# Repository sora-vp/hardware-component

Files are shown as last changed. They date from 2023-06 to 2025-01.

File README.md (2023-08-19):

<p align="center">
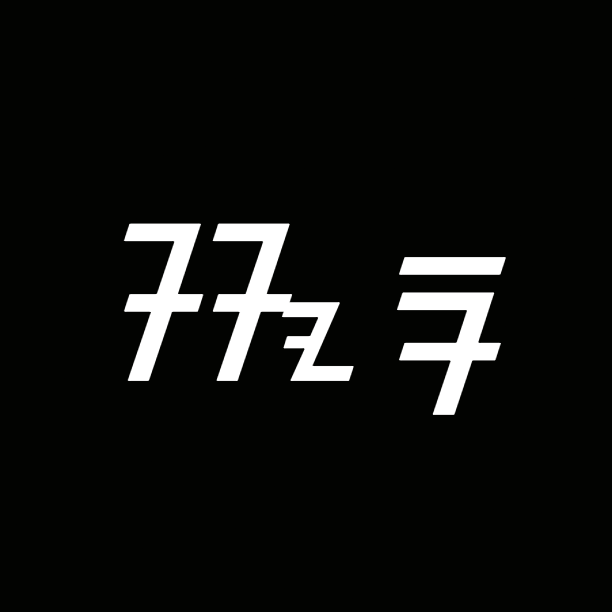
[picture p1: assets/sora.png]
   
   <h1 align="center">SORA BUTTON MODULE</h1>
</p>

Ini adalah repositori pendukung [sora](https://github.com/reacto11mecha/sora) membuat tombol custom untuk memilih kandidat. Harapannya jika tidak ada perangkat touchscreen dan ada orang yang tidak bisa mengoperasikan komputer dengan baik masih bisa ikut memilih seperti biasanya.

## Cara pembuatan tombol custom

Di bawah ini saya akan menjelaskan bagaimana cara membuat modul tombol mandiri. Jika ada hal yang ingin dirubah, silahkan ubah sesuka hati sesuai bahan dan kreativitas masing-masing.

## Siapkan alat bahan

Pertama, siapkan terlebih dahulu alat dan bahan seperti

1. Gunting / cutter
2. Arduino Nano v3.0
3. Kardus bekas
4. Solder
5. Timah
6. Kabel (5 Meter, minimal 16 AWG)
7. Push button (8 buah)
8. Lem tembak beserta isinya.
9. PCB bolong (8x16cm)

> Catatan, untuk kardus dan arduino bisa menyesuaikan budget yang ada. Untuk tutorial di readme ini akan menggunakan kardus sebagai boxnya.

### 1. Buat kerangka

Hasil percobaan yang saya lakukan menghasilkan ukuran kerangka dengan bentuk jaring-jaring balok yang terlihat seperti ini.

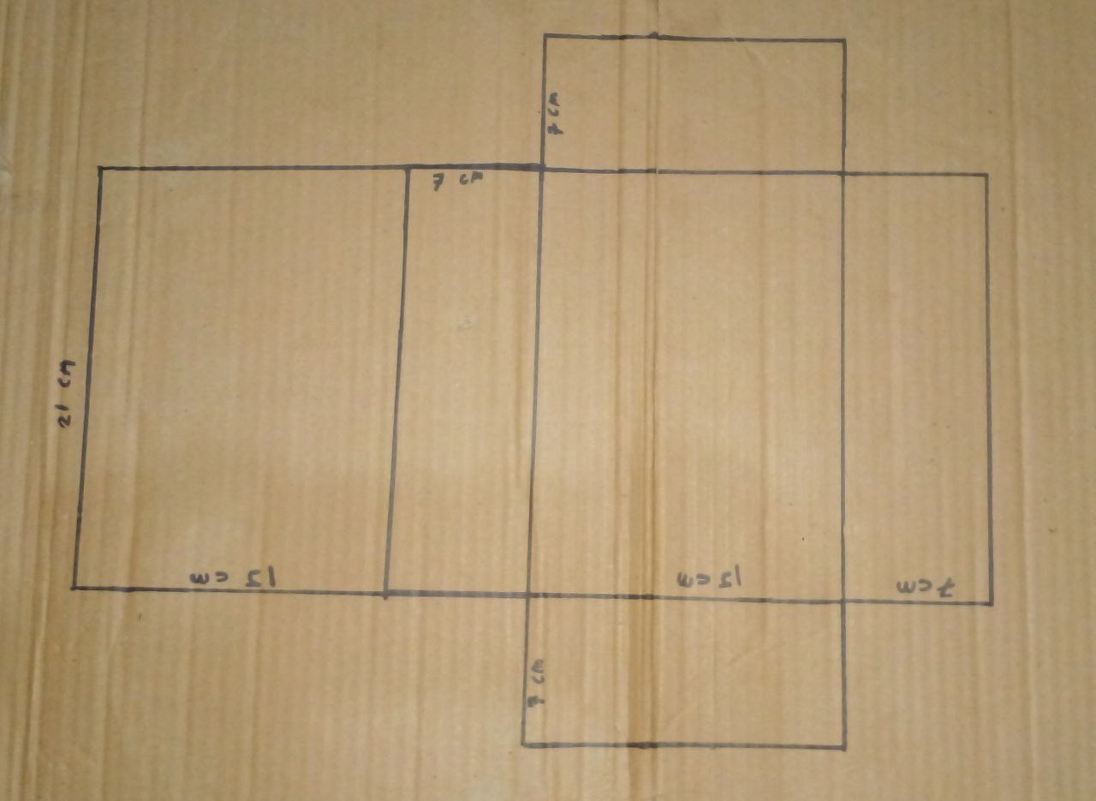
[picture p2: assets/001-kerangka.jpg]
Gambar kerangka kardus


Balok ini memiliki panjang 21 cm, lebar 15 cm, dan tinggi 7 cm.

### 2. Potong setiap bagian sebanyak dua lembar

Jika kerangka sudah dibuat, potong setiap bagian menjadi dua lembar kardus. Kemudian rekatkan menggunakan lem tembak supaya kekuatan kardus tidak terlalu lemah.

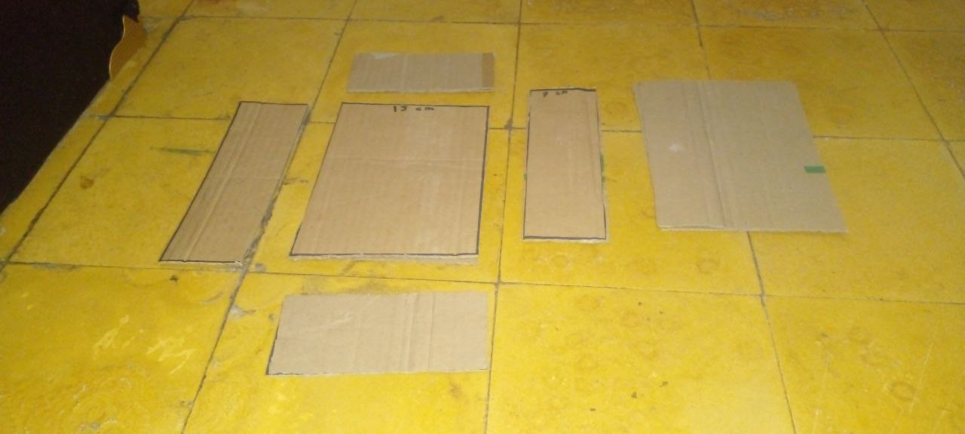
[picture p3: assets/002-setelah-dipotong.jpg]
Gambar bagian-bagian kecil kardus


### 3. Mengatur jarak antar tombol

Untuk penempatan tombol, gunakan jaring-jaring balok dari kardus yang sudah dibuat menggunakan bagian tutup balok.

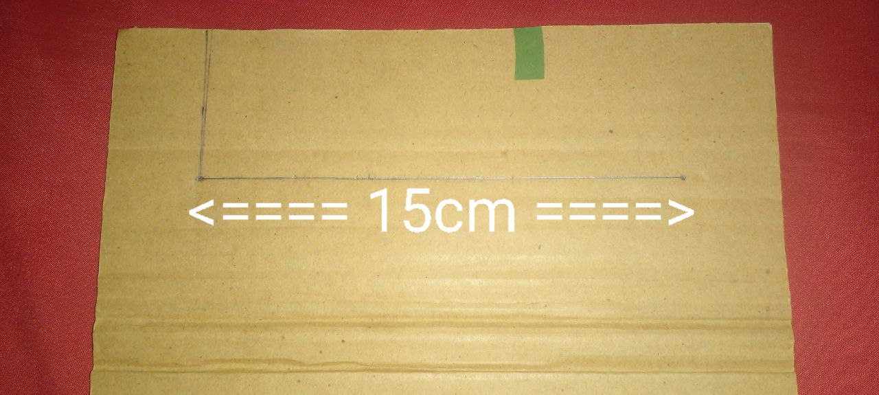
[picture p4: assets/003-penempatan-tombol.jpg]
Ukuran panjang tombol


Panjang keseluruhan peletakan tombol itu 15cm untuk tombol kandidat dan aksi pilih dan pembatalan.

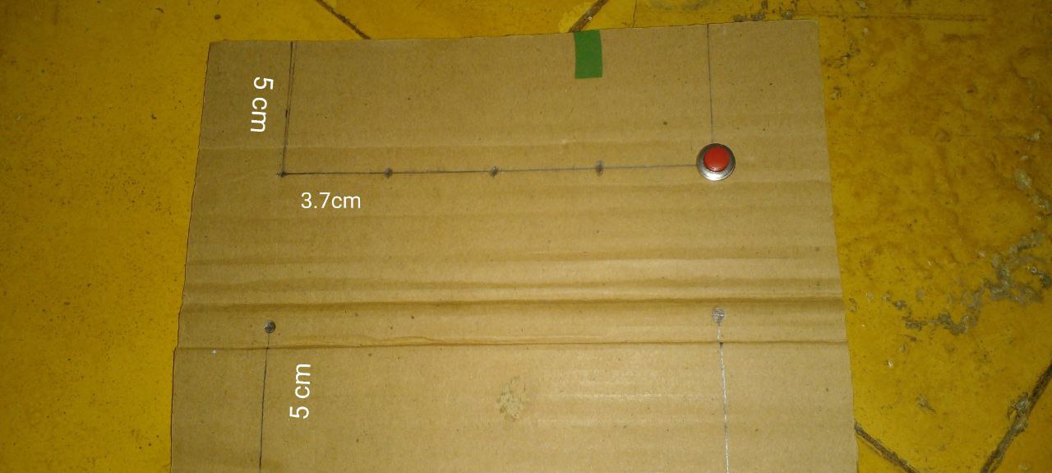
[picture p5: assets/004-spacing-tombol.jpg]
Gambar penjarakan tombol


Untuk tombol angka yang nantinya digunakan untuk memilih kandidat, beri jarak 5cm dari atas juga 3 cm dari kanan dan kiri. Jarak antar tombol memiliki panjang 3.7cm supaya sesuai.

Tombol batal dan pilih juga beri jarak dari bawah. Tombol batal mengikuti posisi tombol nomor 1, sedangkan tombol pilih mengikuti posisi tombol nomor 5.

Tombol reload diposisikan sejajar dengan tombol nomor 5, posisi berjarak 3 cm dari kiri, 3.5 cm dari atas.

Jika sudah pasang lubangi titik-titik yang sudah dibuat, lalu pasang tombol yang sebelumnya sudah disiapkan. Kurang lebih hasilnya akan seperti ini.

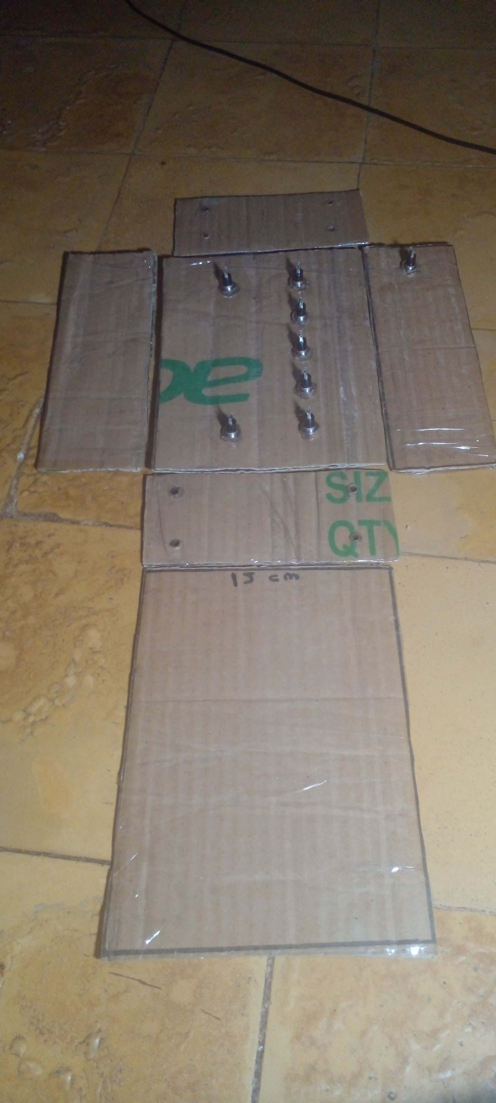
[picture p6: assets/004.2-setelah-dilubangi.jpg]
Gambar 1 setelah sketsa dilubangi


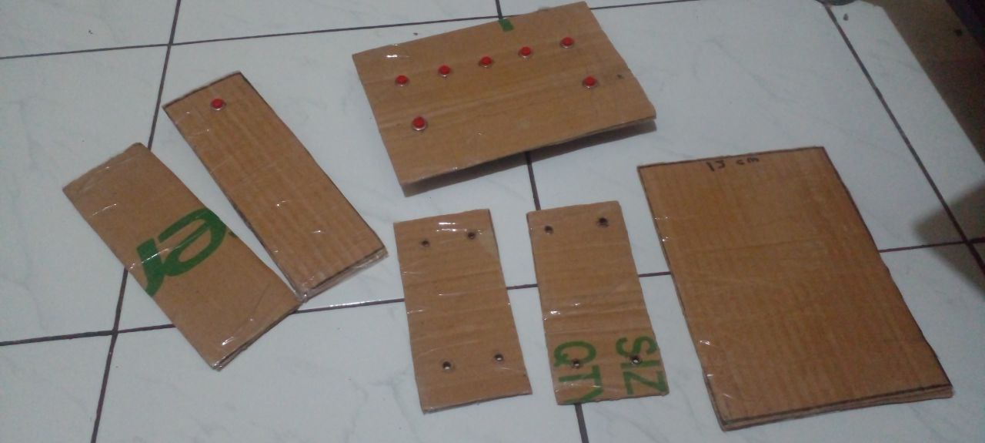
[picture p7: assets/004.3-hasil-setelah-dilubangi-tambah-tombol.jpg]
Gambar 2 setelah sketsa dilubangi


> Jika memperhatikan gambar di atas ada 4 lubang di dua sisi kanan dan kiri kardus, itu berfungsi sebagai lubang udara. Ini opsional tetapi

### 4. Merancang sirkuit

Desain tombol ini sangat berdasar pada artikel [makeuseof.com](https://www.makeuseof.com/tag/make-custom-shortcut-buttons-arduino/) yang membahas cara membuat tombol sendiri. Kurang lebih gambar sirkuitnya sama, yang membedakan saya hanya menggunakan D2 sampai D9 saja.

Gambar sirkuit dari makeuseof

Gambar di atas merupakan gambaran dasar sirkuitnya. Jika diperhatikan pin D2 sampai D9 menggunakan transistor 10k ohm yang warna emas terhubung ke pin arduino, sedangkan seluruh resisto warna coklat akan tersambung ke pin ground atau `GND`.

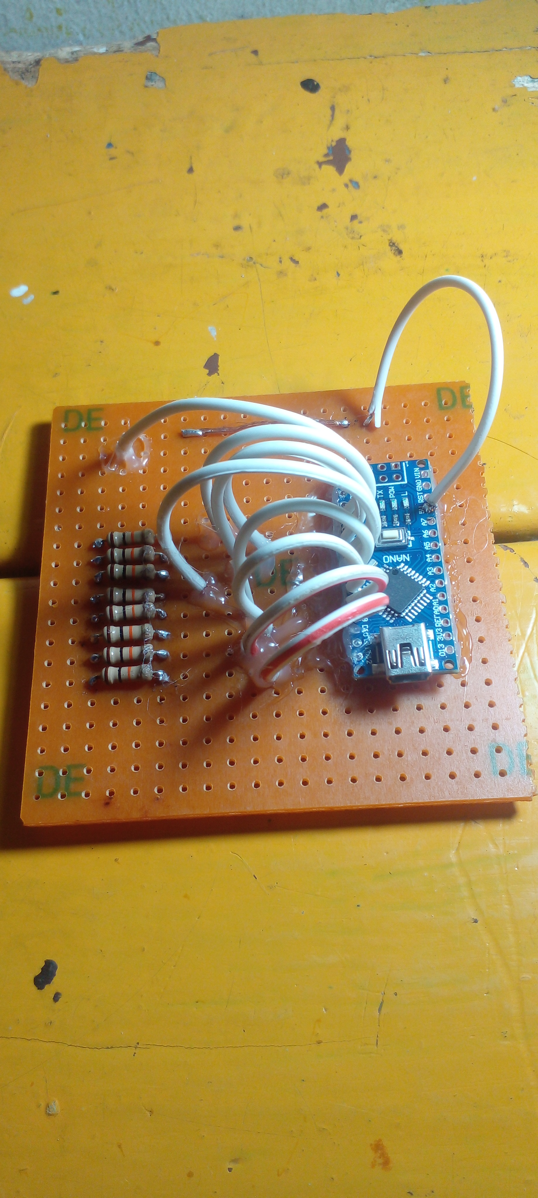
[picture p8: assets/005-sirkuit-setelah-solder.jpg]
Gambar sirkuit setelah di solder


Gambar di atas adalah versi yang nantinya akan digunakan.

### 5. Menambahkan kabel ke tombol dan lem tombol

Jika sudah merancang sirkuitnya, sekarang sambungkan kabel ke tombol dengan cara menyolder kabel supaya sambungannya kuat. Berlaku untuk semua tombol, kira-kira tampaknya akan terlihat seperti dua gambar dibawah ini.

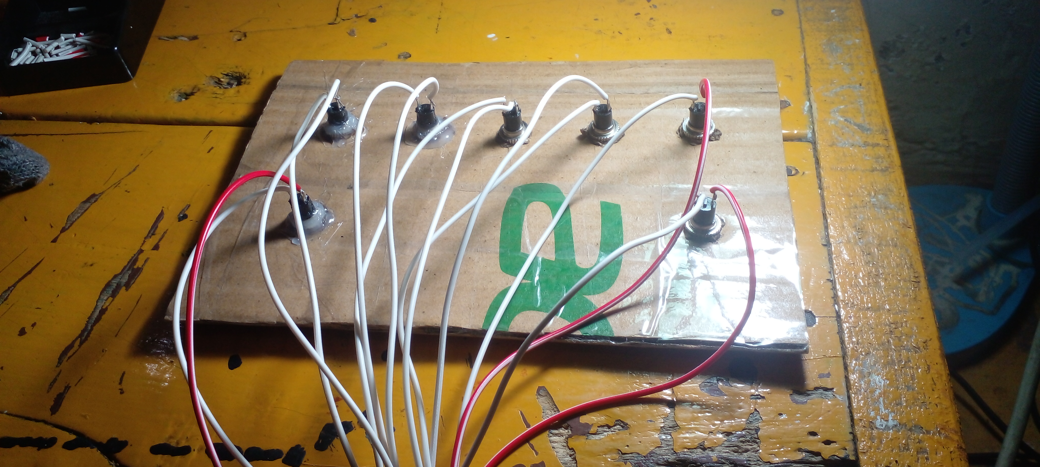
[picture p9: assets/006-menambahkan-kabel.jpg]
Gambar 1 menambahkan kabel ke tombol


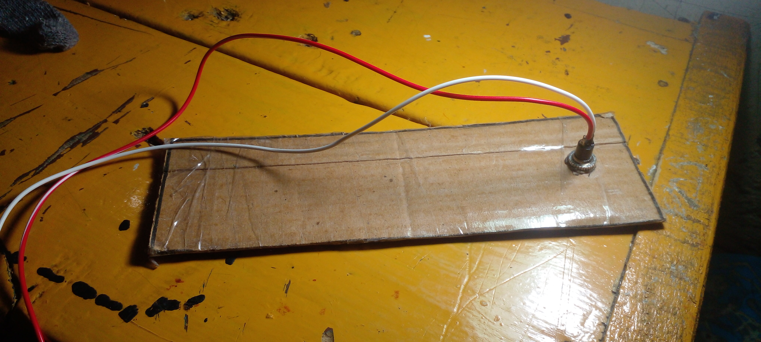
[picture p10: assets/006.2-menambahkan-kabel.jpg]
Gambar 2 menambahkan kabel ke tombol


Jika sudah, lem semua tombol supaya tidak mudah lepas dari kardus. Hal ini juga dapat mengurangi kerusakan jika tombol ditekan terlalu keras.

### 6. Menyambungkan kabel ke sirkuit

Jika sudah menambahkan kabel ke tombol-tombol yang ada, saatnya menyambungkan tombol ke sirkuit yang sudah dibuat sebelumnya. `5V` terhubung ke satu sisi dari tombol, sisi yang lain akan terhubung ke digital pin dari arduino.

Jika berpatokan pada kode di bawah ini,

```ino
const int ESC_PIN = 4;
const int KEYBIND_1_PIN = 9;
const int KEYBIND_2_PIN = 8;
const int KEYBIND_3_PIN = 7;
const int KEYBIND_4_PIN = 6;
const int KEYBIND_5_PIN = 5;
const int ENTER_PIN = 3;
const int RELOAD_PIN = 2;
```

Maka

- Tombol 1 => Pin D9
- Tombol 2 => Pin D8
- Tombol 3 => Pin D7
- Tombol 4 => Pin D6
- Tombol 5 => Pin D5
- Tombol Escape (Kiri Bawah) => Pin D4
- Tombol Enter (Kanan Bawah) => Pin D3
- Tombol Reload (Sisi depan, bersamaan port usb) => Pin D2

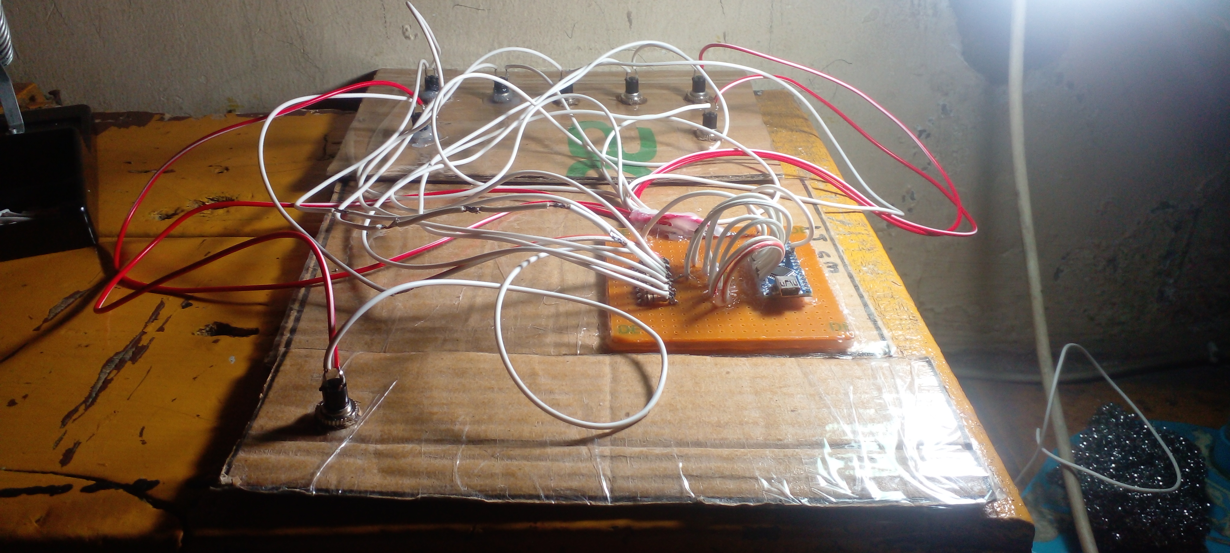
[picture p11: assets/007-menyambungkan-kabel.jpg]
Gambar menyambungkan kabel keseluruhan kabel


Gambar setelah di sambungkan menggunakan solder akan terlihat seperti ini.

> Sekali lagi, sesuaikan dengan kebutuhan

### 7. Memposisikan sirkuit dengan papan reload

Pada tahap ini, posisikan pcb dengan arduino yang sudah di rekatkan dengan kardus yang memiliki tombol reload. Disarkankan posisi yang bisa dipasang port mini usb ke arduino berada berseberangan dengan tombol reload. Jika sudah, buat lubang kotak untuk tempat terhubungnya arduino melalui USB.

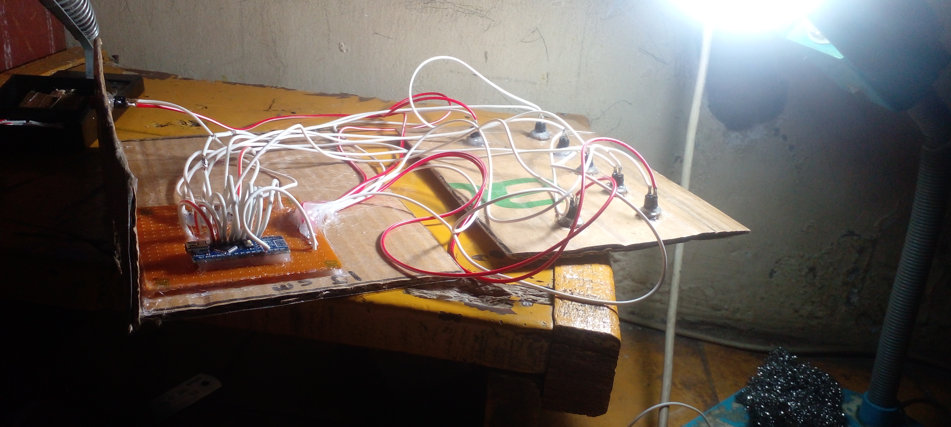
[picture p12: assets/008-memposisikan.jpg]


Tampak depan setelah dilubangi.

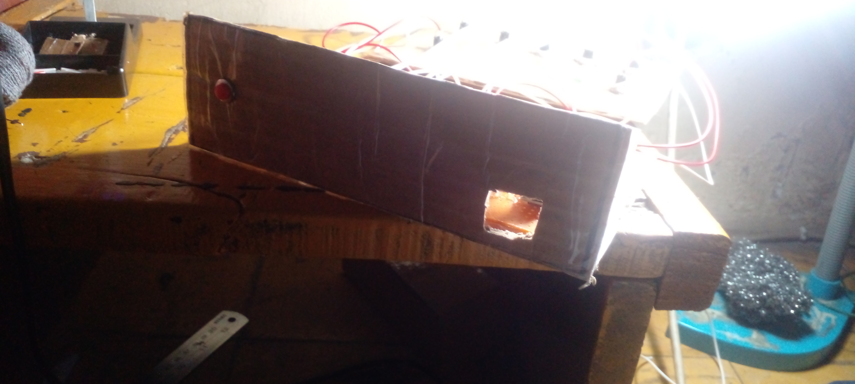
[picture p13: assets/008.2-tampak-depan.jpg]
Tampak depan


### 8. Lem semua komponen

Jika dirasa sudah beres, lem semua komponen yang akhirnya tampak seperti kotak yang memiliki tombol. Hasil akhirnya tampak seperti dibawah ini.

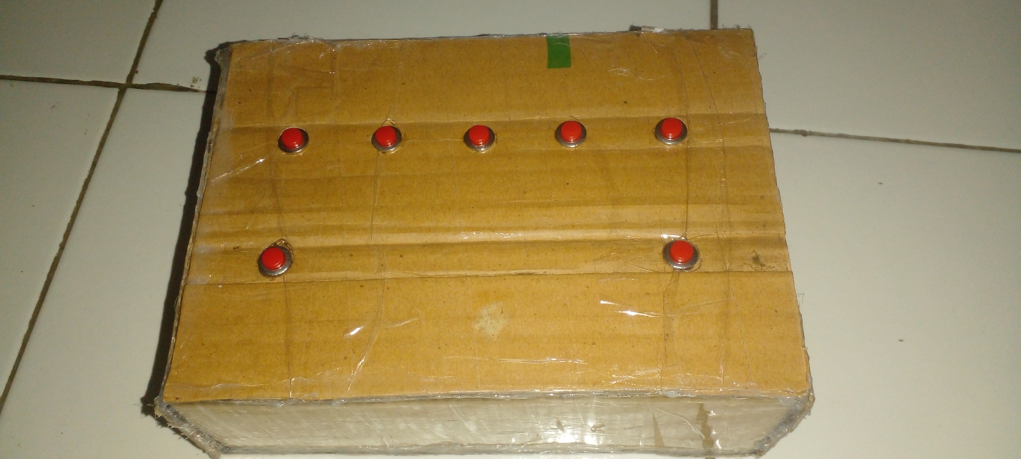
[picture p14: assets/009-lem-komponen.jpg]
Tampak atas setelah di lem


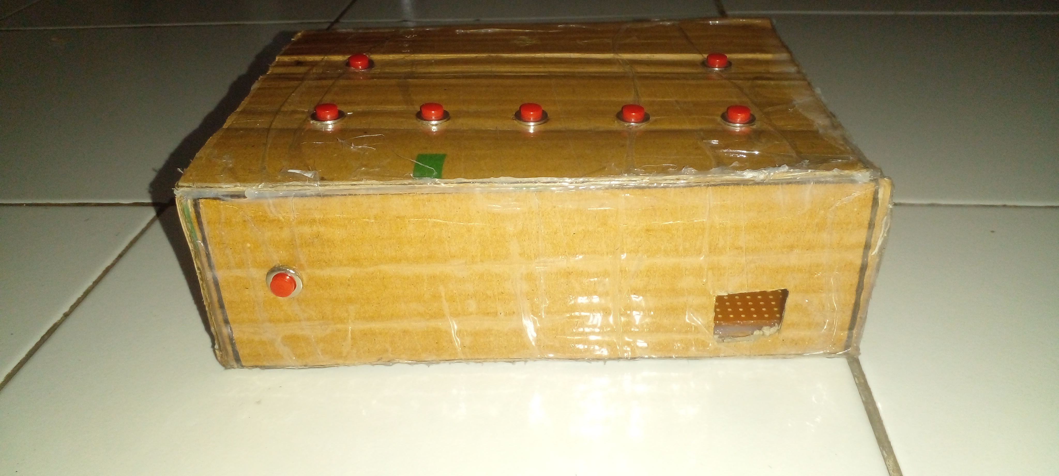
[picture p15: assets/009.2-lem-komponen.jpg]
Tampak depan setelah di lem


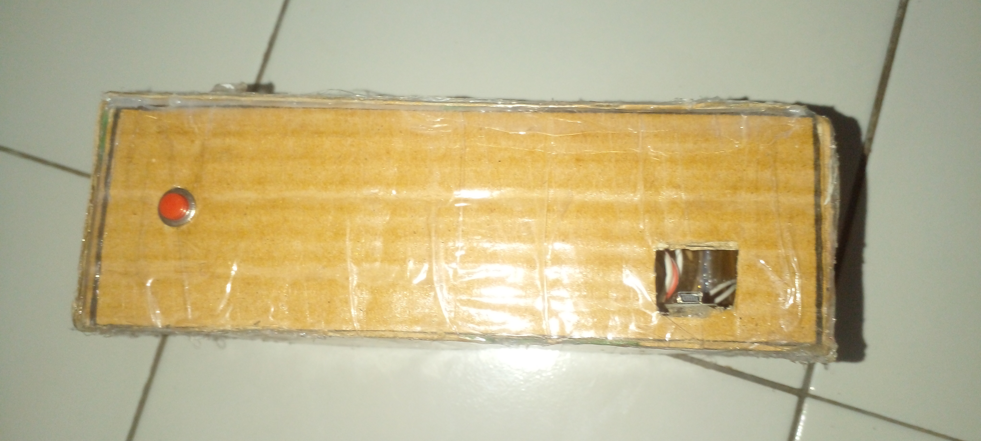
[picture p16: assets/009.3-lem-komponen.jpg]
Tampak sisi depan setelah di lem


### 9. Finishing

Dibagian ini, silahkan di hias dan setiap tombol yang ada diberi keterangan supaya peserta pemilihan mengetahui fungsi dari setiap tombol.

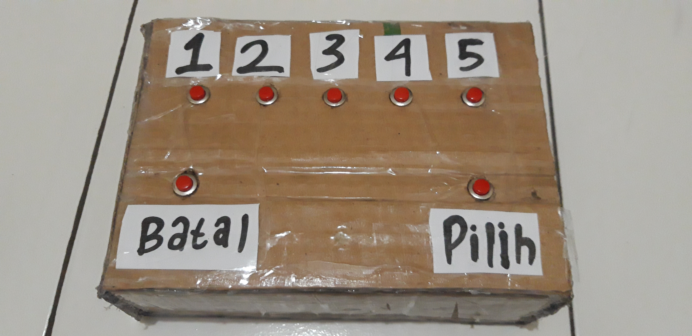
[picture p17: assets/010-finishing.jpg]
Tampak atas setelah finishing


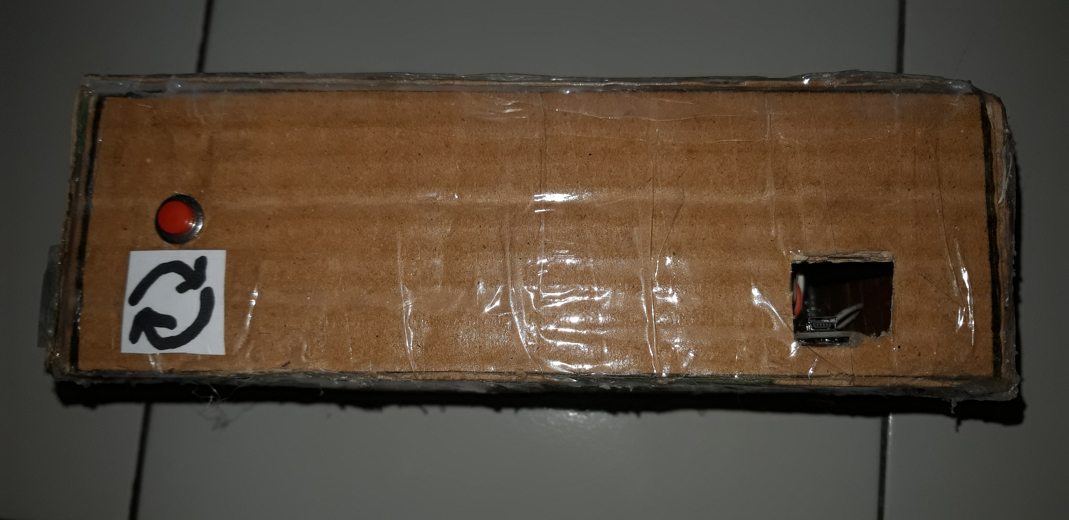
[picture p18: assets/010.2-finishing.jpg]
Tampak depan setelah finishing


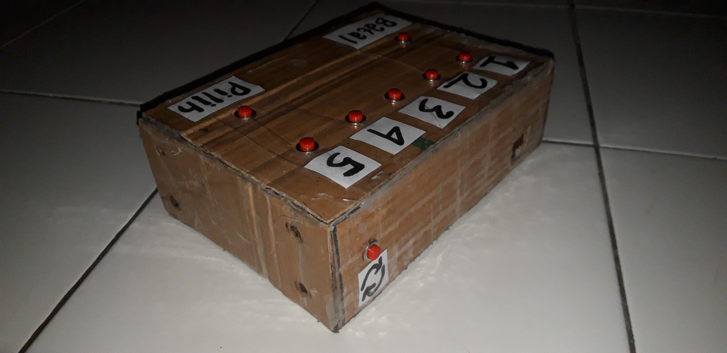
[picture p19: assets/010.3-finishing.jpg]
Tampak sisi depan setelah finishing


## Upload sketch ke arduino

TODO: penjelasan

## Sumber Lain

- https://www.makeuseof.com/tag/make-custom-shortcut-buttons-arduino/

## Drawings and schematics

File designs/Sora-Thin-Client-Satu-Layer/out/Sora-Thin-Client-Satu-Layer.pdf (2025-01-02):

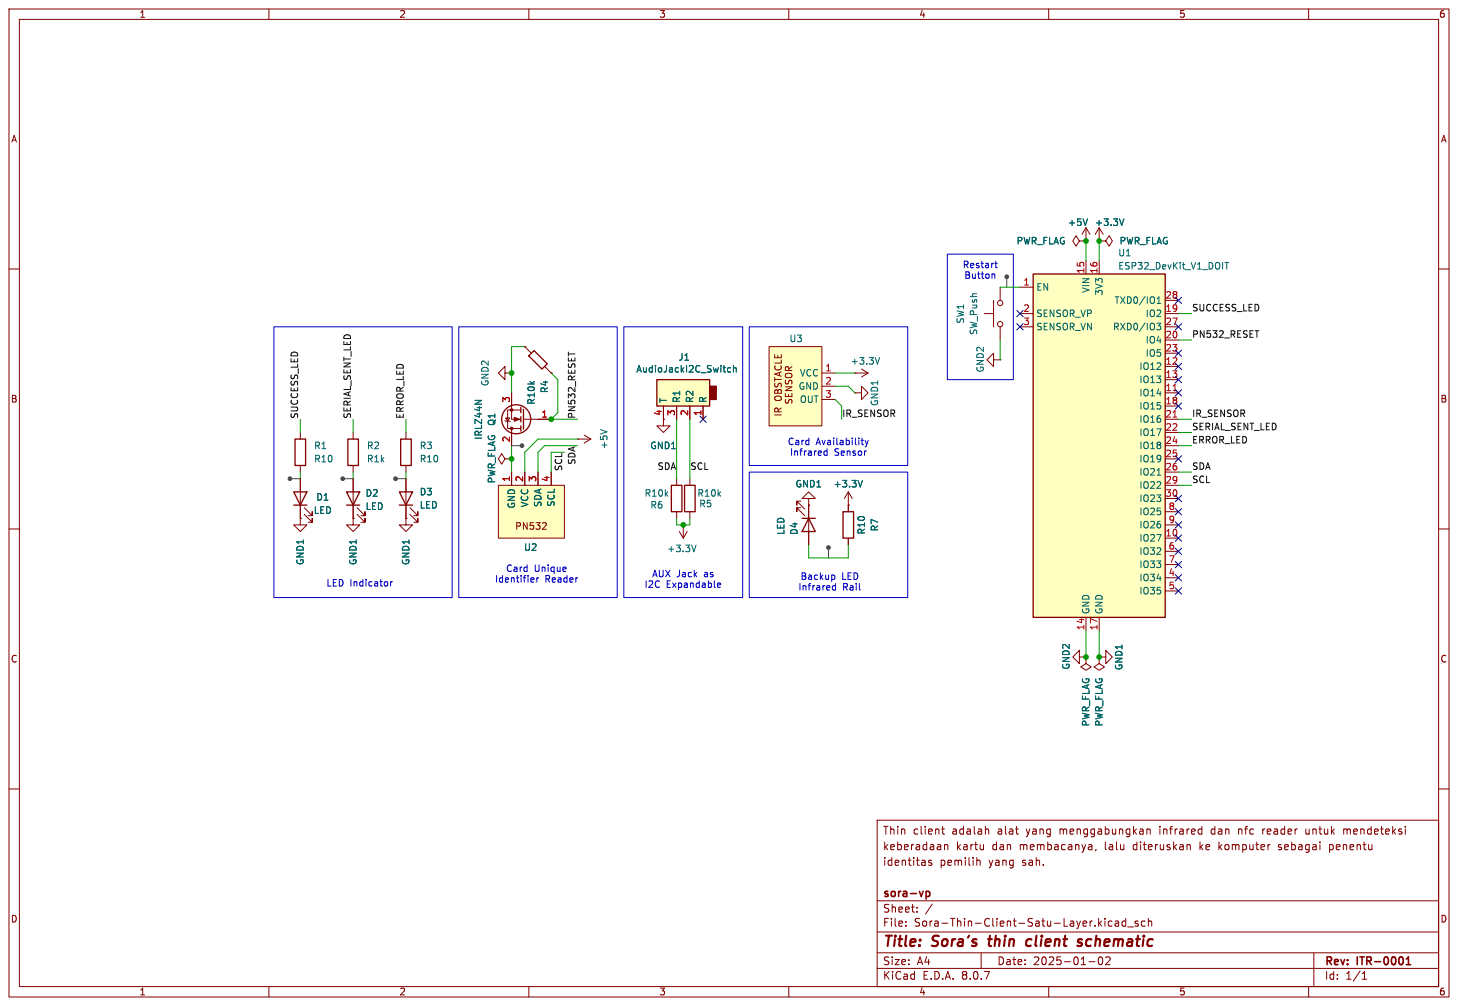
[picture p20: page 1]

Restart Button Card Unique

SENSOR VCC 1 GND 2 OUT 3 U3 R4 R10k GND1 +5V GND2 R10 R7

File: Sora-Thin-Client-Satu-Layer.kicad_sch Sheet: / sora-vp

Id: 1/1 Title: Sora's thin client schematic

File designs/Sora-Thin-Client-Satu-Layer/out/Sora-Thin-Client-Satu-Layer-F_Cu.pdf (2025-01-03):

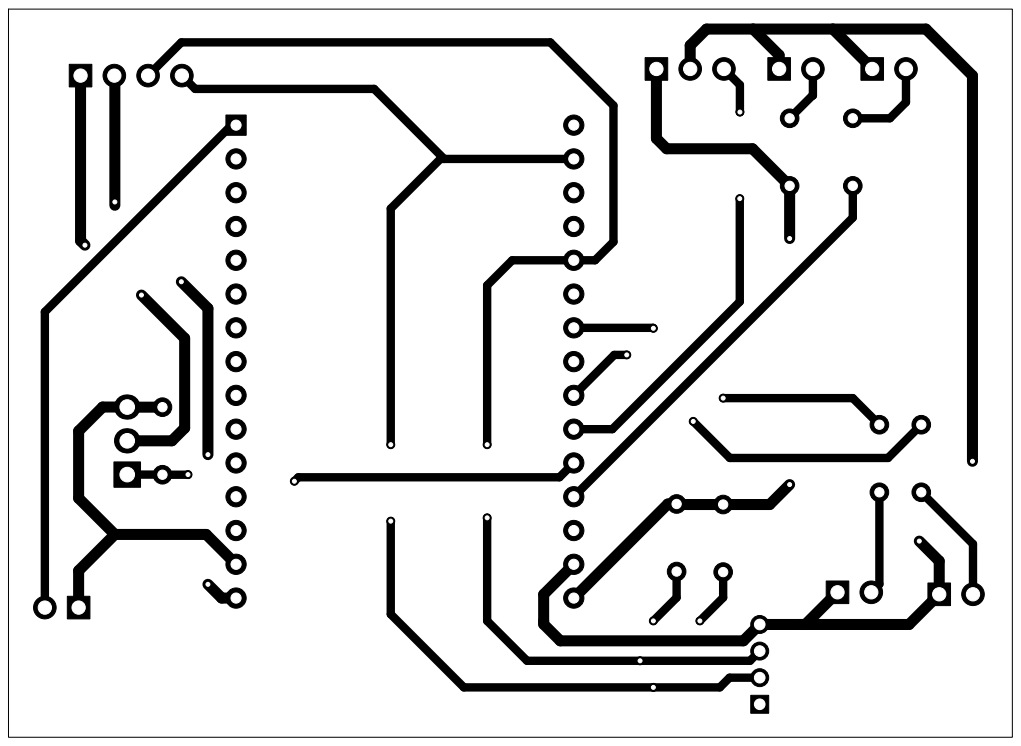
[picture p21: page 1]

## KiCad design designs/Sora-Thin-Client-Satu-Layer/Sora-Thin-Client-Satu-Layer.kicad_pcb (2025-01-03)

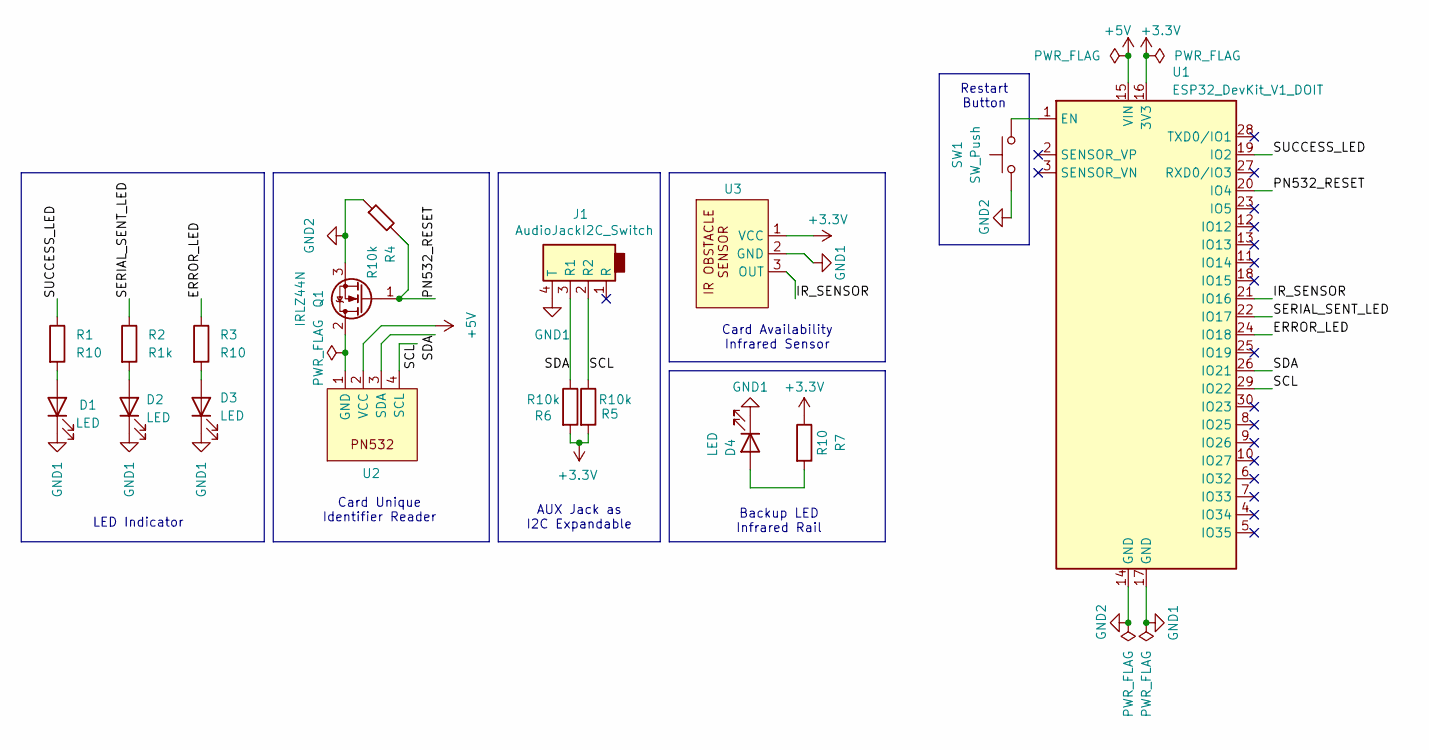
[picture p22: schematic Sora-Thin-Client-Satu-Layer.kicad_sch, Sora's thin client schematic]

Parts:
D1, D2, D3, D4: LED; PinHeader_1x02_P2.54mm_Vertical
J1: AudioJackI2C_Switch; PinHeader_1x04_P2.00mm_Vertical
Q1: IRLZ44N; TO-220-3_Vertical
R1, R3, R7: R10; R_Axial_DIN0204_L3.6mm_D1.6mm_P5.08mm_Horizontal
R2: R1k; R_Axial_DIN0204_L3.6mm_D1.6mm_P5.08mm_Horizontal
R4, R5, R6: R10k; R_Axial_DIN0204_L3.6mm_D1.6mm_P5.08mm_Horizontal
SW1: SW_Push; PinHeader_1x02_P2.54mm_Vertical
U1: ESP32_DevKit_V1_DOIT; esp32_devkit_v1_doit
U2: PinHeader_1x04_P2.54mm_Vertical
U3: PinHeader_1x03_P2.54mm_Vertical

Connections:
+3.3V: R5.2, R6.2, R7.1, U1.16 (3V3), U3.1 (VCC)
+5V: U1.15 (VIN), U2.2 (VCC)
/ERROR_LED: R3.1, U1.24 (IO18)
/IR_SENSOR: U1.21 (IO16), U3.3 (OUT)
/PN532_RESET: Q1.1 (G), R4.2, U1.20 (IO4)
/SCL: J1.2 (R2), R5.1, U1.29 (IO22), U2.4 (SCL)
/SDA: J1.3 (R1), R6.1, U1.26 (IO21), U2.3 (SDA)
/SERIAL_SENT_LED: R2.1, U1.22 (IO17)
/SUCCESS_LED: R1.1, U1.19 (IO2)
GND1: D1.1 (K), D2.1 (K), D3.1 (K), D4.1 (K), J1.4 (T), U1.17 (GND), U3.2 (GND)
GND2: Q1.3 (S), R4.1, SW1.1, U1.14 (GND)
unnamed: D1.2 (A), R1.2
unnamed: D2.2 (A), R2.2
unnamed: D3.2 (A), R3.2
unnamed: D4.2 (A), R7.2
unnamed: Q1.2 (D), U2.1 (GND)
unnamed: SW1.2, U1.1 (EN)

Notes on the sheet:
LED Indicator
AUX Jack as I2C Expandable
Restart Button
Backup LED Infrared Rail
Card Unique Identifier Reader
Card Availability Infrared Sensor

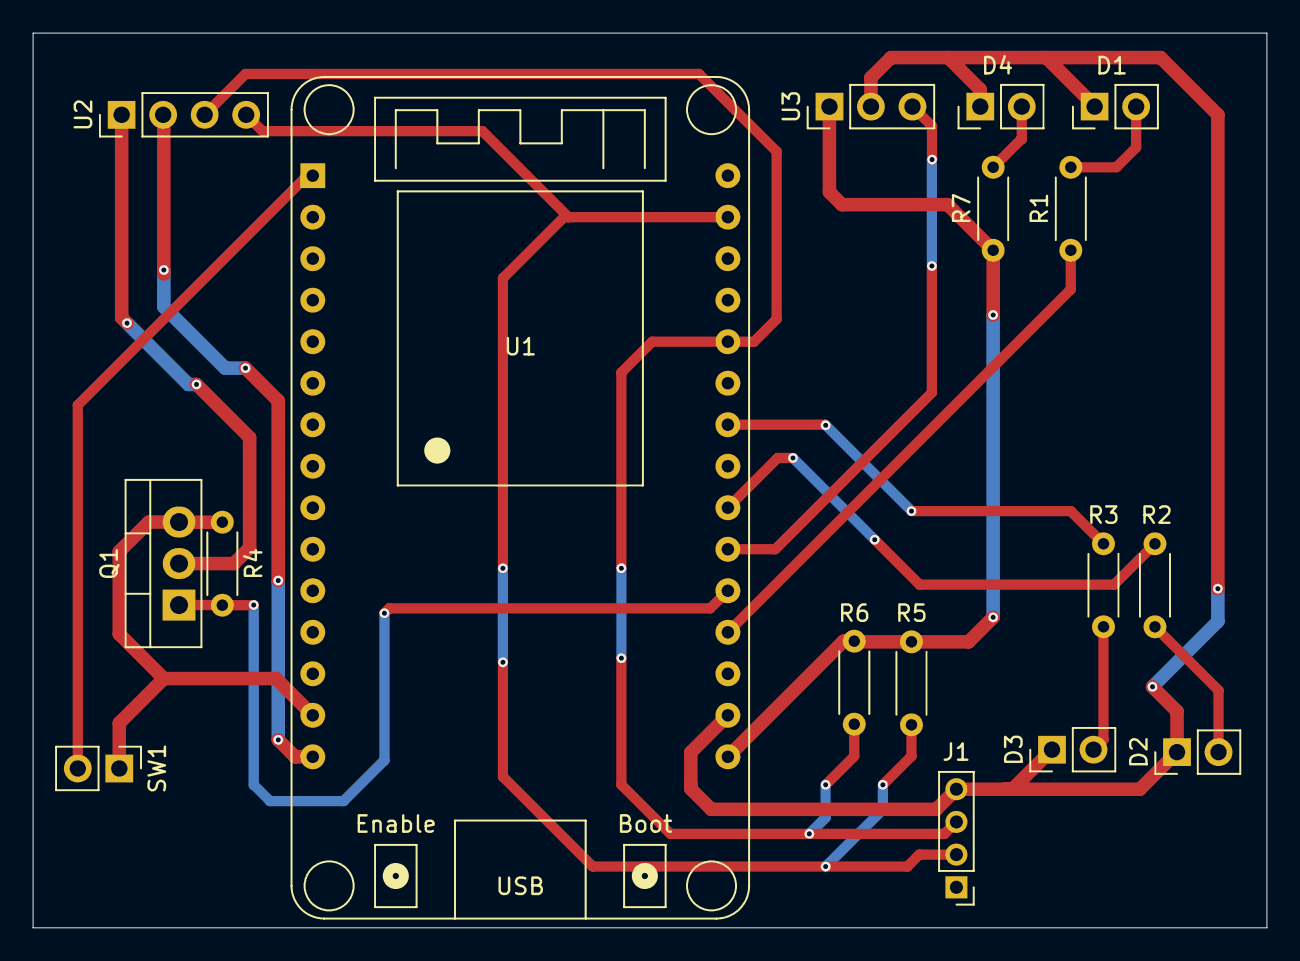
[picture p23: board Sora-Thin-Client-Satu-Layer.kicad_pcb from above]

Board: 2 copper layers, 75.5 x 54.8 mm, 17 parts (0 on the bottom side), 17 nets.

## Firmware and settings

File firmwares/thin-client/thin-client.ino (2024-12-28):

#include <Wire.h>
#include <PN532_I2C.h>
#include <PN532.h>
#include <NfcAdapter.h>

// Pin definitions and button address
#define IR_SENSOR_PIN 16
#define SUCCESSFULLY_DETECTED_LED_PIN 2
#define SERIAL_SENT_LED_PIN 17
#define ERROR_INDICATOR_LED_PIN 18
#define PN532_RESET_TRANSISTOR_PIN 4
#define BUTTON_HARDWARE_ADDRESS 0x1F

// Define queue item size for convenience
#define QUEUE_ITEM_SIZE 55

// Create PN532 instance
PN532_I2C pn532i2c(Wire);
PN532 nfc(pn532i2c);

// Task handles
TaskHandle_t irTaskHandle;
TaskHandle_t nfcTaskHandle;
TaskHandle_t queueTaskHandle;
TaskHandle_t buttonTaskHandle;
TaskHandle_t serialTaskHandle;
TaskHandle_t ledTaskHandle;

// Mutex handle
SemaphoreHandle_t stateMutex;

// Handle string queue of handler
QueueHandle_t stringQueue;
QueueHandle_t ledQueue;

// Define states as an enum
enum MachineState
{
  UNAVAIL_STATE,
  AVAIL_STATE
};
enum LedSuccessState
{
  LED_OFF,
  LED_IR_DETECTED, // 28 brightness
  LED_NFC_DETECTED // 255 brightness
};

unsigned short failedAttempts = 0;
volatile bool isReaderConnected = false;
volatile MachineState currentState = UNAVAIL_STATE; // Default state
String cardUID = "";                                // Stores the UID when in AVAIL_STATE

bool connectToCard()
{
  if (failedAttempts >= 3)
  {
    digitalWrite(PN532_RESET_TRANSISTOR_PIN, HIGH);
    vTaskDelay(1000 / portTICK_PERIOD_MS);
    digitalWrite(PN532_RESET_TRANSISTOR_PIN, LOW);
    vTaskDelay(1000 / portTICK_PERIOD_MS);
    digitalWrite(PN532_RESET_TRANSISTOR_PIN, HIGH);
  }

  nfc.begin();

  uint32_t versiondata = nfc.getFirmwareVersion();
  if (!versiondata)
  {
    Serial.println("PN532 card module not found!");
    return false;
  }

  nfc.setPassiveActivationRetries(0xFF);
  nfc.SAMConfig();

  failedAttempts = 0;
  digitalWrite(ERROR_INDICATOR_LED_PIN, LOW);

  return true;
}

void setup()
{
  Serial.begin(115200);

  pinMode(IR_SENSOR_PIN, INPUT);
  pinMode(SUCCESSFULLY_DETECTED_LED_PIN, OUTPUT);
  pinMode(PN532_RESET_TRANSISTOR_PIN, OUTPUT);
  pinMode(SERIAL_SENT_LED_PIN, OUTPUT);
  pinMode(ERROR_INDICATOR_LED_PIN, OUTPUT);

  digitalWrite(PN532_RESET_TRANSISTOR_PIN, LOW);
  digitalWrite(SERIAL_SENT_LED_PIN, LOW);
  digitalWrite(ERROR_INDICATOR_LED_PIN, HIGH);

  Wire.begin();
  Wire.setClock(10000);

  // Create the mutex
  stateMutex = xSemaphoreCreateMutex();

  if (stateMutex == NULL)
  {
    Serial.println("Failed to create mutex!");
    while (true)
      ; // Halt system if mutex creation fails
  }

  // Create the queue
  stringQueue = xQueueCreate(100, QUEUE_ITEM_SIZE); // Adjust queue length and item size as needed

  if (stringQueue == NULL)
  {
    Serial.println("Failed to create serial string queue!");
    while (true)
      ;
  }

  ledQueue = xQueueCreate(30, sizeof(LedSuccessState));
  if (ledQueue == NULL)
  {
    Serial.println("Failed to create LED queue!");
    while (true)
      ;
  }

  digitalWrite(PN532_RESET_TRANSISTOR_PIN, HIGH);

  isReaderConnected = connectToCard();

  while (!isReaderConnected)
  {
    failedAttempts++;
    Serial.println("Retrying to connect to card module...");
    vTaskDelay(850 / portTICK_PERIOD_MS);
    isReaderConnected = connectToCard();
  }

  digitalWrite(ERROR_INDICATOR_LED_PIN, LOW);

  // Create tasks
  xTaskCreatePinnedToCore(irTask, "IR Sensor Task", 5000, NULL, 1, &irTaskHandle, 1);
  xTaskCreatePinnedToCore(nfcTask, "NFC Reader Task", 6500, NULL, 1, &nfcTaskHandle, 1);
  xTaskCreatePinnedToCore(buttonTask, "External Button Hardware Task", 3000, NULL, 1, &buttonTaskHandle, 1);
  xTaskCreatePinnedToCore(queueManagerTask, "Queue Manager Task", 2000, NULL, 1, &queueTaskHandle, 0);
  xTaskCreatePinnedToCore(serialTask, "Serial Task", 3000, NULL, 1, &serialTaskHandle, 0);
  xTaskCreatePinnedToCore(ledTask, "LED Control Task", 2000, NULL, 1, &ledTaskHandle, 0);
}

void irTask(void *parameter)
{
  while (true)
  {
    bool objectDetected = digitalRead(IR_SENSOR_PIN) == LOW;

    if (objectDetected)
    {
      vTaskResume(nfcTaskHandle); // Wake NFC task

      LedSuccessState ledState = LED_IR_DETECTED;
      xQueueSend(ledQueue, &ledState, 0);
    }
    else
    {
      vTaskSuspend(nfcTaskHandle);

      LedSuccessState ledState = LED_OFF;
      xQueueSend(ledQueue, &ledState, 0);

      // Lock the mutex to update shared state
      if (xSemaphoreTake(stateMutex, portMAX_DELAY))
      {
        currentState = UNAVAIL_STATE;
        cardUID = ""; // Clear the UID

        xSemaphoreGive(stateMutex); // Release the mutex
      }
    }

    vTaskDelay(100 / portTICK_PERIOD_MS); // Poll every 100 ms
  }
}

void nfcTask(void *parameter)
{
  while (true)
  {
    uint8_t uidBuffer[7];
    uint8_t uidLength;

    if (nfc.readPassiveTargetID(PN532_MIFARE_ISO14443A, uidBuffer, &uidLength))
    {
      // Construct UID string
      String uid = "";
      for (uint8_t i = 0; i < uidLength; i++)
      {
        uid += "0x" + String(uidBuffer[i], HEX);
      }
      uid.toUpperCase();

      vTaskSuspend(irTaskHandle);          // Suspend IR task
      vTaskDelay(25 / portTICK_PERIOD_MS); // A small delay

      // Lock the mutex to update shared state
      if (xSemaphoreTake(stateMutex, portMAX_DELAY))
      {
        currentState = AVAIL_STATE;
        cardUID = uid;
        xSemaphoreGive(stateMutex); // Release the mutex
      }

      vTaskDelay(25 / portTICK_PERIOD_MS); // A small delay
      vTaskResume(irTaskHandle);           // Resume IR task
    }
    else
    {
      failedAttempts++;

      digitalWrite(ERROR_INDICATOR_LED_PIN, HIGH);
      vTaskDelay(300 / portTICK_PERIOD_MS);
      digitalWrite(ERROR_INDICATOR_LED_PIN, LOW);
    }

    // Small delay to avoid immediate re-trigger
    vTaskDelay(650 / portTICK_PERIOD_MS);

    // DO NOT REMOVE THIS LINE!
    // PN532 needs to reconnect after every read to refresh I2C context
    // so the this machine still can communicate with the button even
    // on the first boot.
    // So please please please, do not remove this line below.
    isReaderConnected = connectToCard();
  }

  vTaskSuspend(nfcTaskHandle); // Should never reach here
}

void buttonTask(void *param)
{
  char buffer[32]; // Buffer to store the response from the slave

  while (true)
  {
    // Request data from the slave
    Wire.requestFrom(BUTTON_HARDWARE_ADDRESS, sizeof(buffer) - 1);

    // Read the response
    int i = 0;

    while (Wire.available() && i < sizeof(buffer) - 1)
    {
      char c = Wire.read();

      // Filter out non-printable characters
      if (isPrintable(c) && c != '\0')
      {
        buffer[i++] = c;
      }
    }

    buffer[i] = '\0'; // Null-terminate the string

    // Enqueue the received message if it's valid
    if (strlen(buffer) > 0)
    {
      if (strncmp(buffer, "<SORA-KEYBIND-", 14) == 0)
      {
        if (xQueueSend(stringQueue, buffer, pdMS_TO_TICKS(100)) != pdPASS)
        {
          specialQueueFullError();
        }
      }
    }

    vTaskDelay(50 / portTICK_PERIOD_MS); // Adjust polling interval as needed
  }
}

void queueManagerTask(void *parameter)
{
  while (true)
  {
    MachineState localState;
    String localUID;

    // Lock the mutex to read shared state
    if (xSemaphoreTake(stateMutex, portMAX_DELAY))
    {
      localState = currentState;
      localUID = cardUID;
      xSemaphoreGive(stateMutex); // Release the mutex
    }

    // Use local copies of the state to avoid holding the mutex too long
    String message;
    if (localState == UNAVAIL_STATE)
    {
      message = "<SORA-THIN-CLIENT-DATA-UNAVAIL>";
    }
    else if (localState == AVAIL_STATE)
    {
      message = "<SORA-THIN-CLIENT-DATA-" + localUID + ">";

      LedSuccessState ledState = LED_NFC_DETECTED;
      xQueueSend(ledQueue, &ledState, 0);
    }

    // Send the message to the queue
    if (xQueueSend(stringQueue, message.c_str(), pdMS_TO_TICKS(100)) != pdPASS)
    {
      specialQueueFullError();
    }

    vTaskDelay(localState == UNAVAIL_STATE ? 100 / portTICK_PERIOD_MS : 200 / portTICK_PERIOD_MS); // Adjust delay as needed
  }
}

void serialTask(void *parameter)
{
  char buffer[QUEUE_ITEM_SIZE]; // Buffer for dequeued message

  while (true)
  {

    if (xQueueReceive(stringQueue, buffer, portMAX_DELAY))
    {
      Serial.println(buffer);

      digitalWrite(SERIAL_SENT_LED_PIN, HIGH);
      vTaskDelay(25 / portTICK_PERIOD_MS);
      digitalWrite(SERIAL_SENT_LED_PIN, LOW);
    }
    else
    {
      vTaskDelay(25 / portTICK_PERIOD_MS); // Small delay to avoid busy-waiting
    }
  }
}

void ledTask(void *parameter)
{
  LedSuccessState currentState = LED_OFF;
  LedSuccessState lastReceivedState = LED_OFF;

  unsigned long lastUpdateTime = 0;        // Timestamp for last state change
  const unsigned long debounceDelay = 150; // Value between 100ms (irTask, queueManagerTask) and 200ms (queueManagerTask)

  while (true)
  {
    LedSuccessState newState;

    if (xQueueReceive(ledQueue, &newState, portMAX_DELAY))
    {
      // Only consider state changes after the debounce delay
      unsigned long currentTime = millis();

      if (newState != lastReceivedState)
      {
        lastReceivedState = newState; // Update the last received state

        // Apply the new state only if debounce delay has passed
        if (currentTime - lastUpdateTime >= debounceDelay || newState == LED_OFF)
        {
          lastUpdateTime = currentTime; // Update the last change timestamp
          currentState = newState;

          switch (currentState)
          {
          case LED_OFF:
            analogWrite(SUCCESSFULLY_DETECTED_LED_PIN, 0);
            break;
          case LED_IR_DETECTED:
            analogWrite(SUCCESSFULLY_DETECTED_LED_PIN, 13);
            break;
          case LED_NFC_DETECTED:
            analogWrite(SUCCESSFULLY_DETECTED_LED_PIN, 255);
            break;
          }
        }
      }
    }

    vTaskDelay(10 / portTICK_PERIOD_MS); // Small delay to reduce task overhead
  }
}

void loop()
{
  // Leave this empty
  delay(1000);
}

// Hope this function will never execute
void specialQueueFullError()
{
  for (short i = 0; i <= 5; i++)
  {

    digitalWrite(ERROR_INDICATOR_LED_PIN, HIGH);
    vTaskDelay(200 / portTICK_PERIOD_MS);
    digitalWrite(ERROR_INDICATOR_LED_PIN, LOW);
  }
}

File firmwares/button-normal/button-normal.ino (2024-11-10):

const int debounceDelay = 50; // in ms
const int NUM_KEYS = 8;

const int keys[NUM_KEYS] = {2, 3, 4, 5, 6, 7, 8, 9};
int buttonState[NUM_KEYS];
int lastButtonState[NUM_KEYS];
unsigned long lastDebounceTime[NUM_KEYS];

const int ESC_PIN = 4;
const int KEYBIND_1_PIN = 9;
const int KEYBIND_2_PIN = 8;
const int KEYBIND_3_PIN = 7;
const int KEYBIND_4_PIN = 6;
const int KEYBIND_5_PIN = 5;
const int ENTER_PIN = 3;
const int RELOAD_PIN = 2;

bool awaitingAck = false;

void setup()
{
  // Init serial
  Serial.begin(9600);

  // Init pin registered on keys
  for (int i = 0; i < NUM_KEYS; i++)
  {
    pinMode(keys[i], INPUT_PULLUP);
    lastButtonState[i] = digitalRead(keys[i]);
  }
}

void loop()
{
  if (awaitingAck)
  {
    if (Serial.available() > 0)
    {
      char ack = Serial.read();

      if (ack == 'A')
      {
        awaitingAck = false;
      }
    }
  }
  else
  {
    for (int i = 0; i < NUM_KEYS; i++)
    {
      int reading = digitalRead(keys[i]);

      if (reading != lastButtonState[i])
      {
        lastDebounceTime[i] = millis();
      }

      if ((millis() - lastDebounceTime[i]) > debounceDelay)
      {
        if (reading != buttonState[i])
        {
          buttonState[i] = reading;

          if (buttonState[i] == LOW)
          {
            doAction(keys[i]);
          }
        }
      }

      lastButtonState[i] = reading;
    }
  }
}

void doAction(int pin)
{
  switch (pin)
  {
  case ESC_PIN:
    Serial.println("<SORA-KEYBIND-ESC>");
    break;
  case RELOAD_PIN:
    Serial.println("<SORA-KEYBIND-RELOAD>");
    break;
  case KEYBIND_1_PIN:
    Serial.println("<SORA-KEYBIND-1>");
    break;
  case KEYBIND_2_PIN:
    Serial.println("<SORA-KEYBIND-2>");
    break;
  case KEYBIND_3_PIN:
    Serial.println("<SORA-KEYBIND-3>");
    break;
  case KEYBIND_4_PIN:
    Serial.println("<SORA-KEYBIND-4>");
    break;
  case KEYBIND_5_PIN:
    Serial.println("<SORA-KEYBIND-5>");
    break;
  case ENTER_PIN:
    Serial.println("<SORA-KEYBIND-ENTER>");
    break;
  }

  awaitingAck = true;
}

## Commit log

2023-03-16 feat: menambahkan pin dan action
2023-03-16 chore: tetap menggunakan println
2024-07-08 fix: memperbaiki bug windows yang harusnya di baca SORA malah ORA
2024-12-17 feat: menambahkan thin client dan button mini
2024-12-18 fix: menggunakan vector untuk mengganti queue
    [button-mini-thin-client-expandable.ino]
2024-12-25 feat: menambahkan LED yang menjadi indikator pekerjaan mesin
2024-12-26 fix: memperbaiki bug I2C karena tidak refresh status koneksi ke PN532 dan format dokumen
    [button-mini-thin-client-expandable.ino, thin-client.ino]
2024-12-26 fix: memperbaiki bug gagal dalam copy buffer
    [thin-client.ino]
2024-12-27 fix: menambahkan toleransi berapa lama vector pada button
    Saat first boot dan kartu belum di colok si thin client masih bisa komunikasi sama tombol, namun ketika kartu di lepas pasang pada timing dimana I2C bisa aja ga lanjut di baris 169 thin client, nah komunikasi I2C buat di button juga ikut nge-hang karena ketahan di thin client, oleh karena itu daripada pusing benerin thin client, si vector di button ditambahin TTL sebagai toleransi berapa lama data bisa ada di vektor itu sebelum data di flush, takutnya kalo idle dan ada kartu yang nyolok, button ngirimin data stale yang tombol di tekan sama pemilih sebelumnya kekirim, padahal bukan maksud dari pemilih yang sekarang.
    [button-mini-thin-client-expandable.ino, thin-client.ino]
2024-12-28 fix: menambahkan iterasi error supaya trigger mekanisme refresh koneksi
    [thin-client.ino]
2025-01-02 feat: menambahkan skematik dan design pcb menggunakan kicad (2 Layer)
    [Sora-Thin-Client-Dua-Layer.kicad_pcb, Sora-Thin-Client-Dua-Layer.kicad_sch]
2025-01-02 fix: memperbaiki referensi yang rusak karena rename
    [Sora-Thin-Client-Dua-Layer.kicad_pcb, Sora-Thin-Client-Dua-Layer.kicad_sch]
2025-01-02 feat: menambahkan design pcb yang bisa di print manual
    [Sora-Thin-Client-Satu-Layer.kicad_pcb, Sora-Thin-Client-Satu-Layer.kicad_sch]
2025-01-02 fix: memperbaiki jalur dan tidak rotate design
    [Sora-Thin-Client-Satu-Layer.kicad_pcb]
2025-01-02 fix: lampu wajib horizontal
    [Sora-Thin-Client-Satu-Layer.kicad_pcb]
2025-01-03 fix: memperlebar ukuran supaya mudah pada saat solder
    bersama coach sam dkk
    [Sora-Thin-Client-Satu-Layer.kicad_pcb, Sora-Thin-Client-Satu-Layer.kicad_sch]
